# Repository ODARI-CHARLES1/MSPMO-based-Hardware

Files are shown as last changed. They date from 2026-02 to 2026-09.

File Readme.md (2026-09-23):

# MSPM0G350x Development Board

A hardware design for an Arduino UNO form-factor development board featuring the Texas Instruments MSPM0G350x Mixed-Signal Microcontroller with built-in CAN-FD interface.

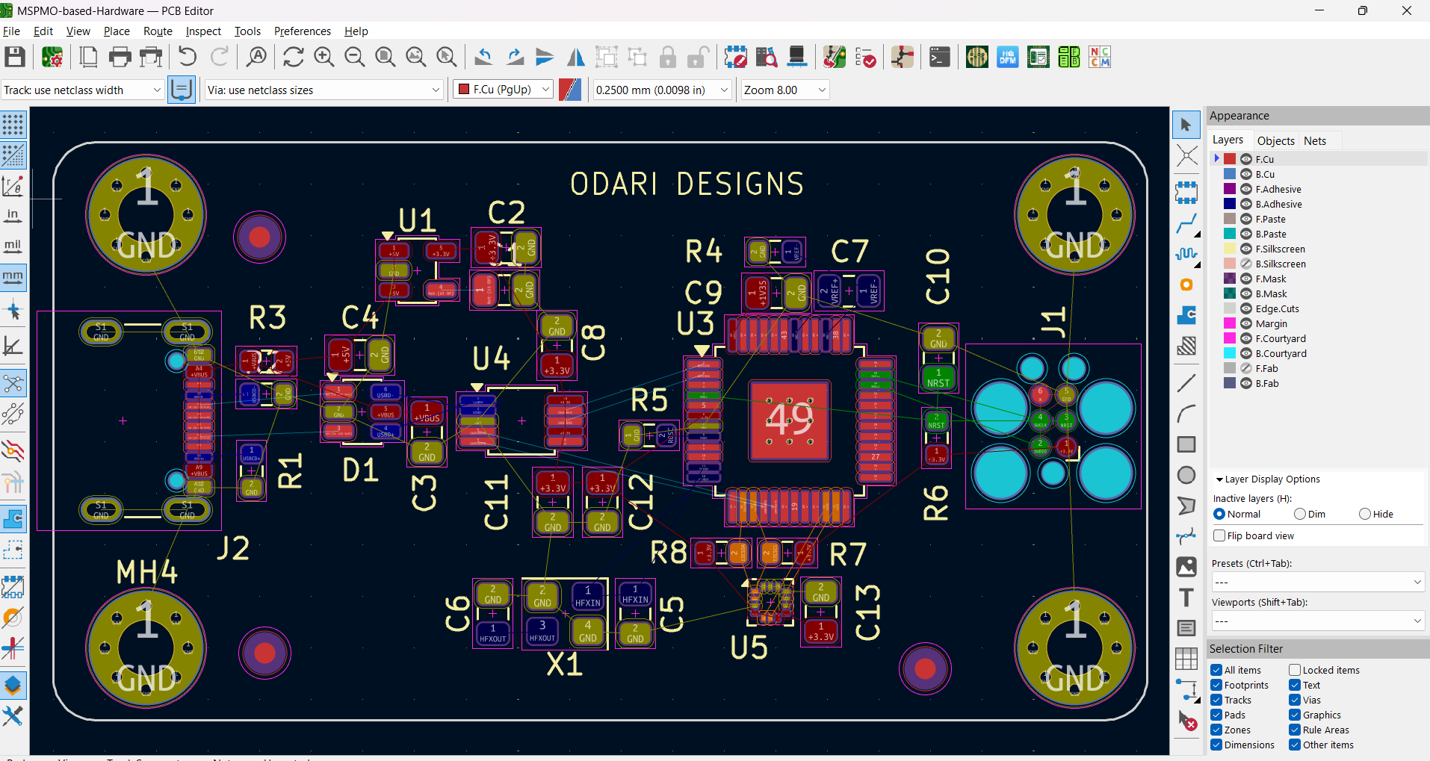
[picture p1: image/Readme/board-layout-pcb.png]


---

## Overview

This project contains the KiCad design files for a custom development board based on the Texas Instruments MSPM0G3507 MCU, featuring CAN-FD connectivity in a familiar Arduino UNO-compatible form factor.

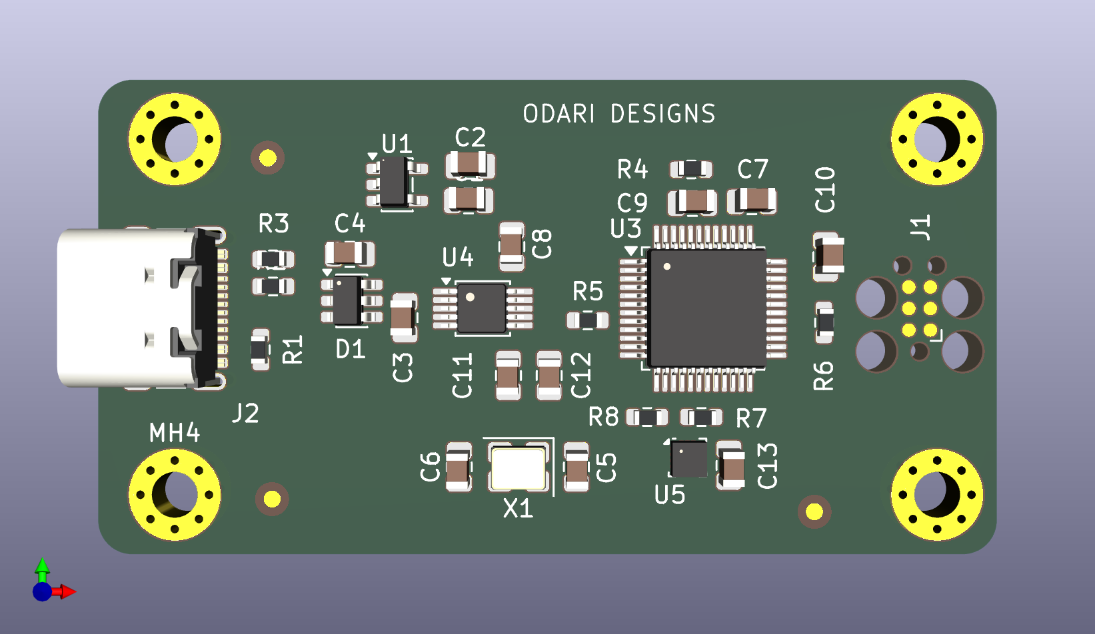
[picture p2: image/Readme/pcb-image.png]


---
## Features

### Microcontroller

- **MCU**: Texas Instruments MSPM0G3507 (or MSPM0G3506)
- **Core**: ARM Cortex-M0+ 32-bit processor
- **Clock Speed**: Up to 80 MHz
- **Flash Memory**: 128 KB (MSPM0G3507) / 64 KB (MSPM0G3506)
- **SRAM**: 32 KB

### Integrated Peripherals

- **CAN-FD Controller**: Built-in CAN-FD with up to 5 Mbps
- **ADC**: 12-bit Analog-to-Digital Converter (up to 20 channels)
- **DAC**: 12-bit Digital-to-Analog Converter (2 channels)
- **Timers**: Multiple 16-bit and 32-bit timers
- **PWM**: High-resolution PWM outputs
- **Communication**: UART, SPI, I2C, DMA

### Board Features

- **Form Factor**: Arduino UNO R3 compatible (2.54mm pitch, 3.3V logic)
- **Power Supply**: 7-12V DC barrel jack or USB-C (5V)
- **USB Interface**: Integrated USB-C for programming and debug
- **CAN Connector**: Standard DB9 or 4-pin header for CAN-FD
- **Power LED**: Power indicator
- **User LED**: Programmable status LED on GPIO pin

---

## Pinout

### Arduino-Compatible Headers

#### Power Pins

| Pin  | Function | Description |
| ---- | --- | --- |
| VIN  | Power Input | External power (7-12V) |
| 5V | 5V Output | Regulated 5V (max 500mA) |
| 3.3V | 3.3V Output | Regulated 3.3V (max 300mA) |
| GND  | Ground | Common ground |
| GND  | Ground | Common ground |
| AREF | Analog Ref  | Analog reference voltage |
| SDA  | I2C Data | I2C data line (PA10) |
| SCL  | I2C Clock | I2C clock line (PA11) |

#### Digital I/O Pins (Right Header)

| Pin | Arduino | MSPM0 Pin | Function |
| --- | --- | --- | --- |
| D0  | RX0 | PA8 | UART0 RX / GPIO |
| D1  | TX0 | PA9 | UART0 TX / GPIO |
| D2  | INT0 | PA7 | External Interrupt / GPIO |
| D3  | PWM | PA6 | PWM / GPIO |
| D4  | - | PA5 | GPIO |
| D5  | PWM | PA4 | PWM / GPIO |
| D6  | PWM | PA3 | PWM / GPIO |
| D7  | - | PA2 | GPIO |

#### Digital I/O Pins (Left Header)

| Pin | Arduino  | MSPM0 Pin | Function |
| --- | --- | --- | --- |
| D8  | - | PC5 | GPIO |
| D9  | PWM | PC4 | PWM / GPIO |
| D10 | SPI SS | PC3 | SPI CS / GPIO |
| D11 | SPI MOSI | PC2 | SPI MOSI / GPIO |
| D12 | SPI MISO | PC1 | SPI MISO / GPIO |
| D13 | SPI SCK  | PC0 | SPI SCK / GPIO  |

#### Analog Pins (Bottom Header)

| Pin | Arduino  | MSPM0 Pin | Function |
| --- | --- | --- | --- |
| A0  | ADC0 | PA26 | ADC Channel 0 |
| A1  | ADC1 | PA27 | ADC Channel 1 |
| A2  | ADC2 | PA28 | ADC Channel 2 |
| A3  | ADC3 | PA25 | ADC Channel 3 |
| A4  | ADC4/SDA | PA10 | ADC / I2C SDA |
| A5  | ADC5/SCL | PA11 | ADC / I2C SCL |

### CAN-FD Interface

| Pin | Function | Notes |
| ----- | --- | --- |
| CAN_H | CAN High | Requires 120Ω termination |
| CAN_L | CAN Low  | Requires 120Ω termination |
| GND | Ground | Signal ground |

---

## Electrical Specifications

| Parameter | Value |
| --- | --- |
| Operating Voltage | 3.3V (logic), 5V (USB power) |
| Input Voltage (Barrel) | 7-12V DC |
| Max Current (3.3V) | 300 mA |
| Max Current (5V USB) | 500 mA |
| I/O Voltage | 3.3V (5V tolerant inputs) |
| CAN-FD Speed | Up to 5 Mbps |
| Operating Temp | -40°C to 85°C |

---

## Mechanical Specifications

| Parameter | Value |
| --- | --- |
| Board Dimensions | 68.6mm × 53.3mm (UNO form factor) |
| Mounting Holes | 4× M3 holes (2.9mm diameter) |
| Header Pitch | 2.54mm (0.1") |
| PCB Thickness | 1.6mm |

---

## Getting Started

### Prerequisites

- Texas Instruments MSPM0 MCU SDK
- CMSIS-DAP or compatible debug probe
- Arduino IDE with MSPM0 support

### Programming

1. **Via Debugger**: Connect a CMSIS-DAP probe to the SWD pins (SWDIO, SWDCLK, GND)
2. **Via USB**: Use the built-in USB bootloader (if programmed)

### Software Setup

```bash
# Install MSPM0 SDK
git clone https://github.com/TexasInstruments/mspm0_sdk.git

# Install ARM GCC toolchain
# Download from: https://developer.arm.com/tools-and-software/open-source-software/developer-tools/gnu-toolchain/gnu-rm
```

---

## Development Tools

- **EDA**: KiCad 8.0+
- **MCU SDK**: TI MSPM0 SDK
- **IDE**: TI Code Composer Studio or VS Code with MSPM0 plugins
- **Programmer**: CMSIS-DAP compatible probe

---

## Project Structure

```
MSPMO-based-Hardware/
├── MSPMO-based-Hardware.kicad_pro    # KiCad project file
├── MSPMO-based-Hardware.kicad_sch    # Schematic
├── MSPMO-based-Hardware.kicad_pcb    # PCB layout
├── MSPMO-based-Hardware.kicad_prl    # Layout settings
├── MSPMO-based-Hardware.kicad_dru    # Design rules
└── Readme.md                         # This file
```

---

## Hardware Design

### Power Supply Circuit

- USB-C connector for 5V input
- Barrel jack for 7-12V DC input
- AMS1117-3.3 LDO for 3.3V regulation
- LM1117-5.0 LDO for 5V regulation (optional)

### CAN-FD Transceiver

- SN65HVD230 or MCP2562 CAN-FD transceiver
- 120Ω terminating resistor (selectable)
- ESD protection on CAN lines

### Additional Components

- Reset button
- Boot selector (for bootloader)
- Power LED (green)
- User LED (red, on PC7)
- Crystal oscillator (32.768 kHz for RTC)

---

## Programming Examples

### Basic Blink

```c
#include "ti_mspm0g3507.h"

int main(void) {
    // Configure PC7 as output (User LED)
    GPIOC->DIR_b.PIN7 = GPIO_DIR_OUT;
  
    while(1) {
        GPIOC->DOUT_BSET = (1 << 7);  // LED on
        delay_ms(500);
        GPIOC->DOUT_BCLR = (1 << 7);  // LED off
        delay_ms(500);
    }
}
```

### CAN-FD Transmit

```c
#include "ti_mspm0g3507.h"
#include "can.h"

int main(void) {
    CAN_Init(CAN_BAUD_500K);
  
    CAN_TxHeaderTypeDef txHeader;
    txHeader.Id = 0x123;
    txHeader.DLC = 8;
    txHeader.IDE = CAN_ID_STD;
    txHeader.FDF = CAN_FD_CAN;
  
    uint8_t data[8] = {0x01, 0x02, 0x03, 0x04, 0x05, 0x06, 0x07, 0x08};
  
    while(1) {
        CAN_SendMessage(&txHeader, data);
        delay_ms(1000);
    }
}
```

---

## License

This hardware design is provided as-is for educational and development purposes.

---

## References

- [TI MSPM0G3507 Datasheet](https://www.ti.com/lit/ds/symlink/mspm0g3507.pdf)
- [TI MSPM0 SDK Documentation](https://dev.ti.com/tirex/explore/node?node=AGJ7H6JRK1A-jhO1mH3k0pw__LATEST)
- [CAN-FD Specification](https://www.can-cia.org/can-fd/)
- [Arduino UNO R3 Reference Design](https://store.arduino.cc/arduino-uno-rev3)

---

## Support

For issues or questions:

- Open an issue on the project repository
- Check TI's E2E forums for MSPM0-specific questions

---

**Version**: 1.0
**Date**: February 2026
**Author**: Odari-Designs

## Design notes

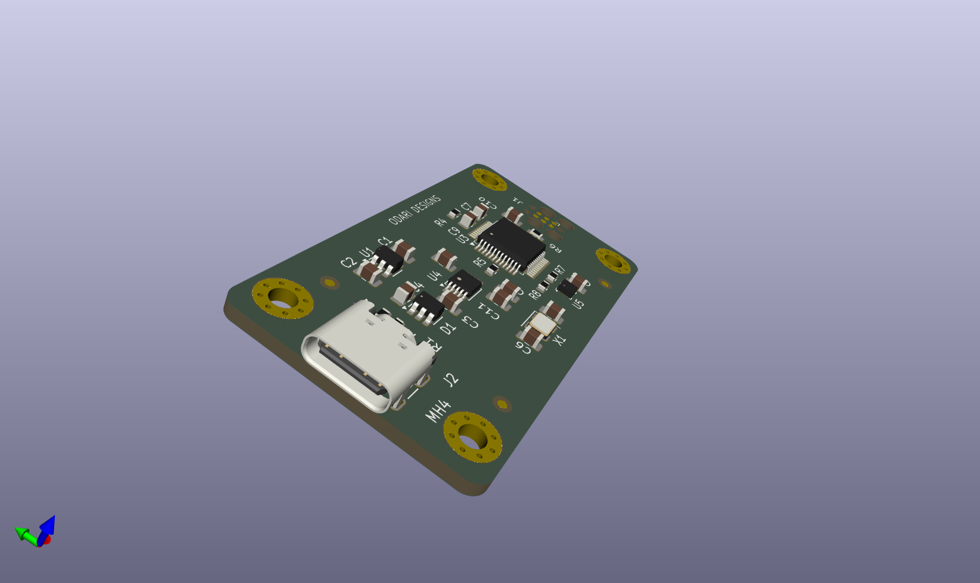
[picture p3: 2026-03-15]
Images/MSPMO-based-Hardware-01.png

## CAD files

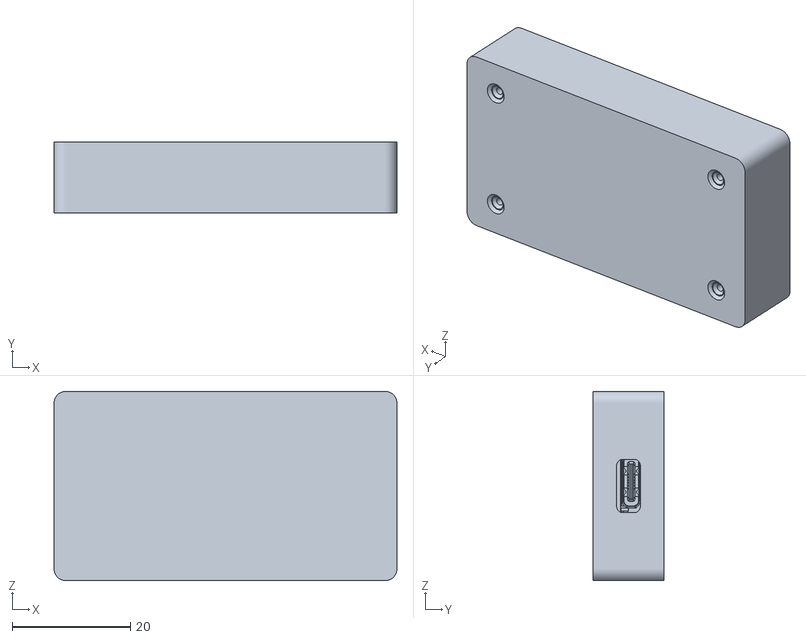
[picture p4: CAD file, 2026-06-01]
Enclosure_design/enclosure_assembly.stl
58.0 x 12.0 x 32.0

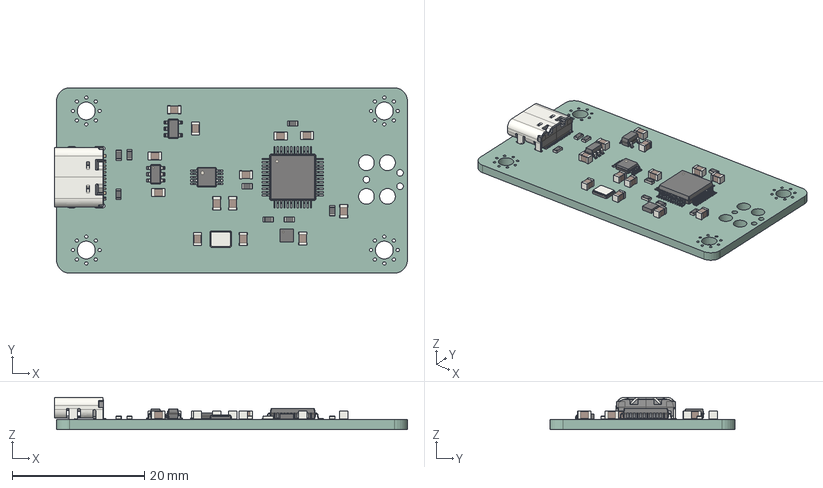
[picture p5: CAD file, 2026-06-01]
MSPMO-based-Hardware.step
53.3 x 28.0 x 4.91 mm
C_0805_2012Metric x 13
LGA-14_2x2mm_P0.35mm_LayoutBorder3x4y
USB_C_Receptacle_GCT_USB4105-xx-A_16P_TopMnt_Horizontal
R_0603_1608Metric x 8
Crystal_SMD_3225-4Pin_3.2x2.5mm
LQFP-48-1EP_7x7mm_P0.5mm_EP3.6x3.6mm
SOT-23-5
SOT-23-6
MSOP-10_3x3mm_P0.5mm
MSPMO-based-Hardware_PCB

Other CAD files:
Enclosure_design/MSPMO-based-Hardware.step
MSPMO-based-Hardware.stl

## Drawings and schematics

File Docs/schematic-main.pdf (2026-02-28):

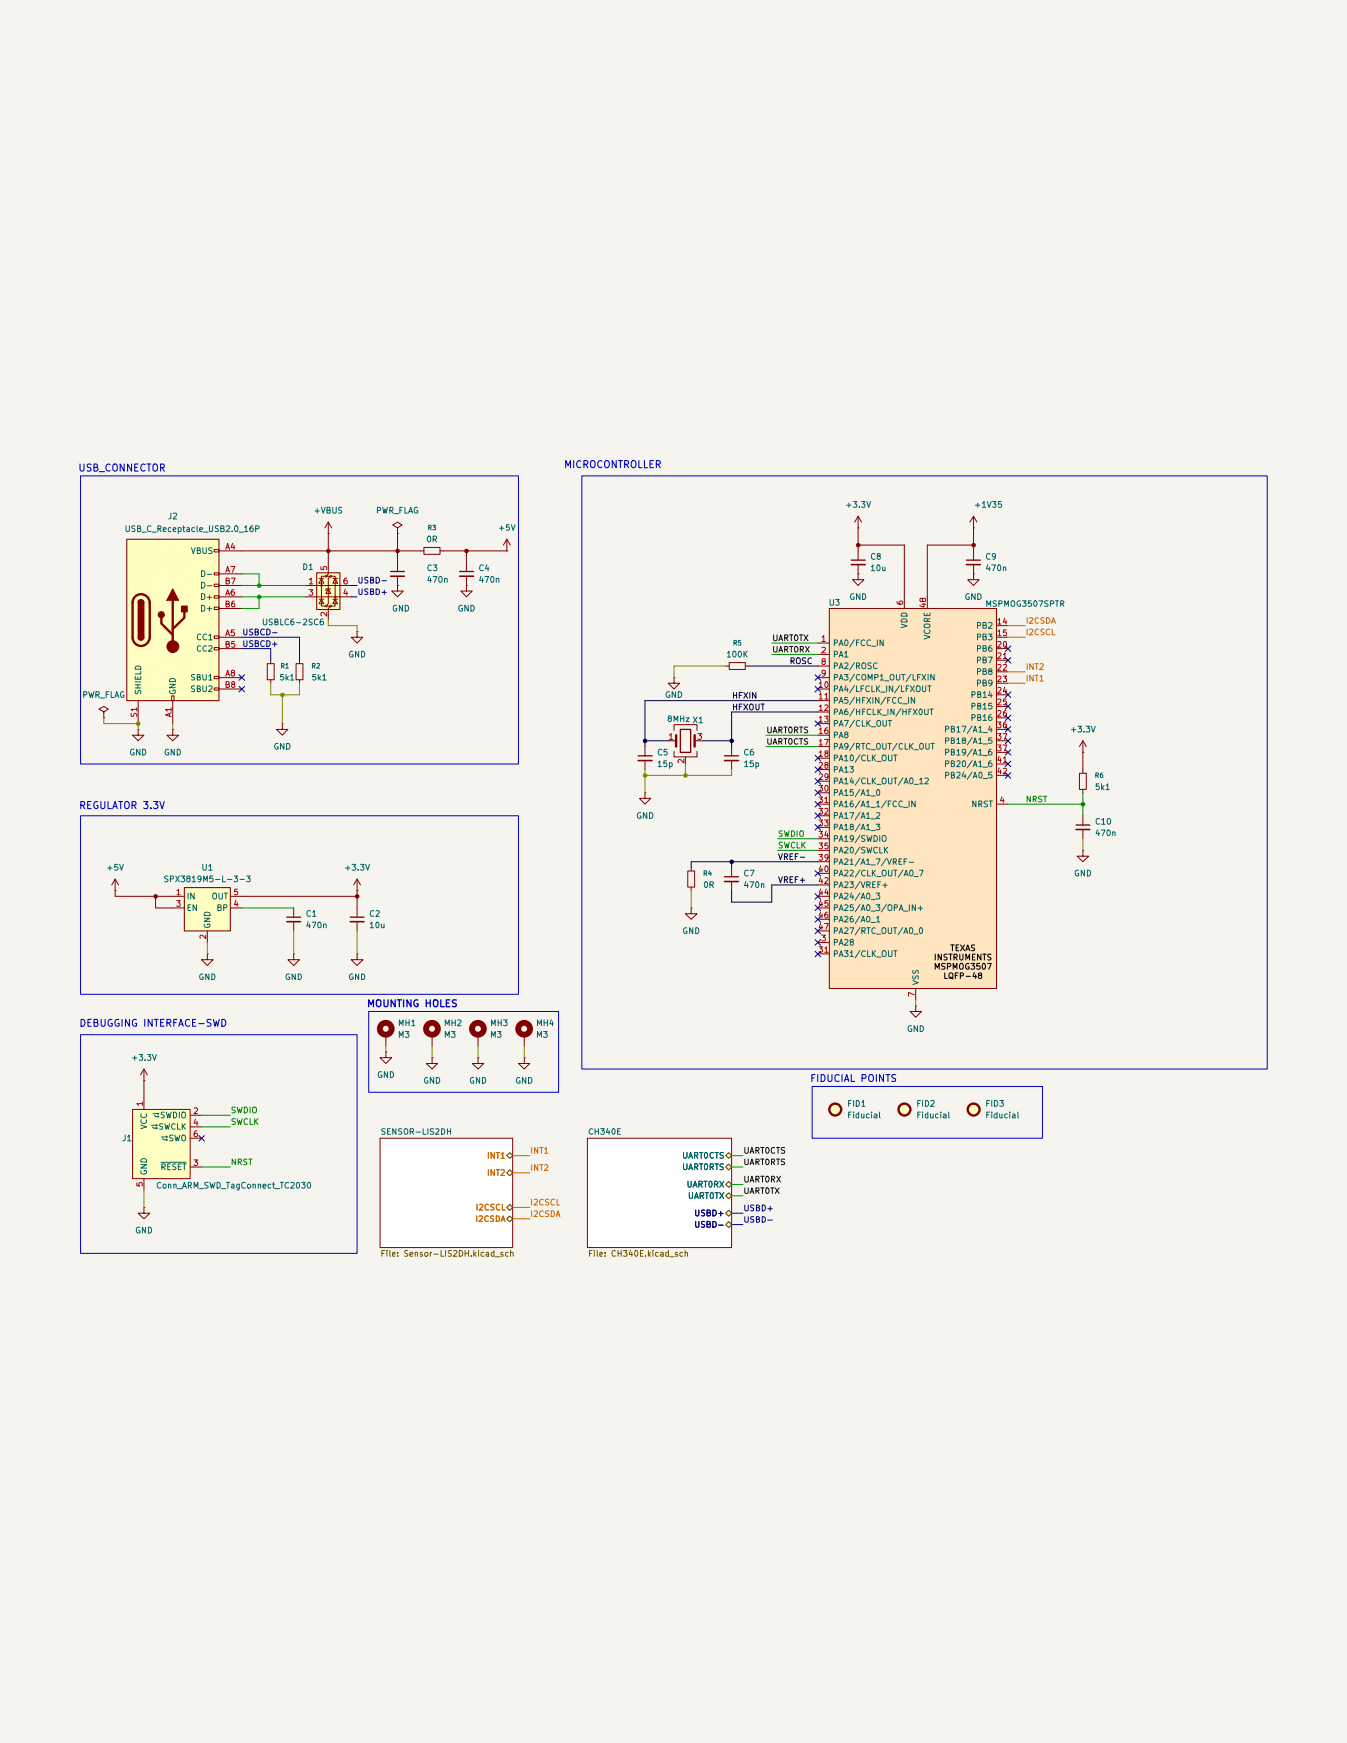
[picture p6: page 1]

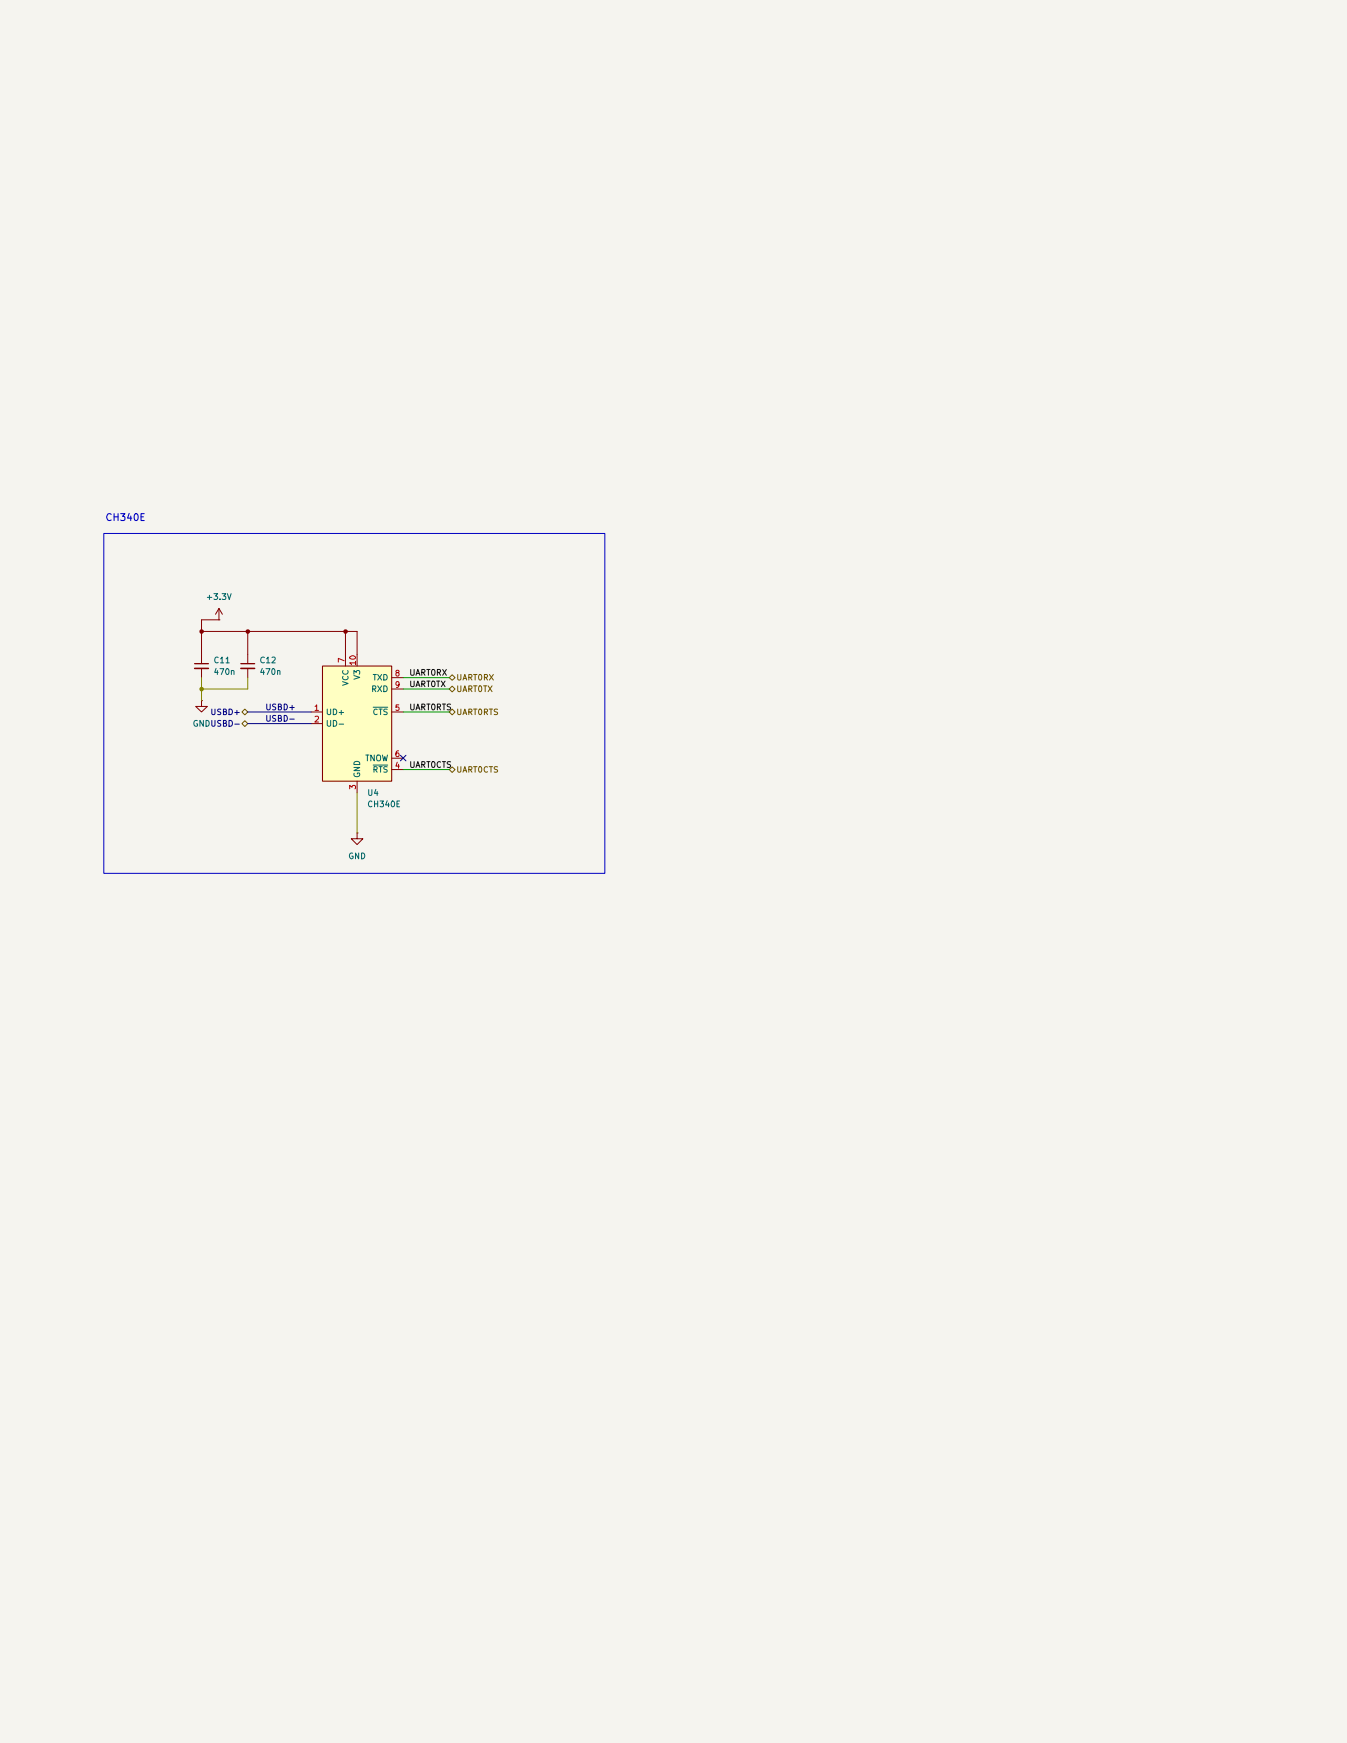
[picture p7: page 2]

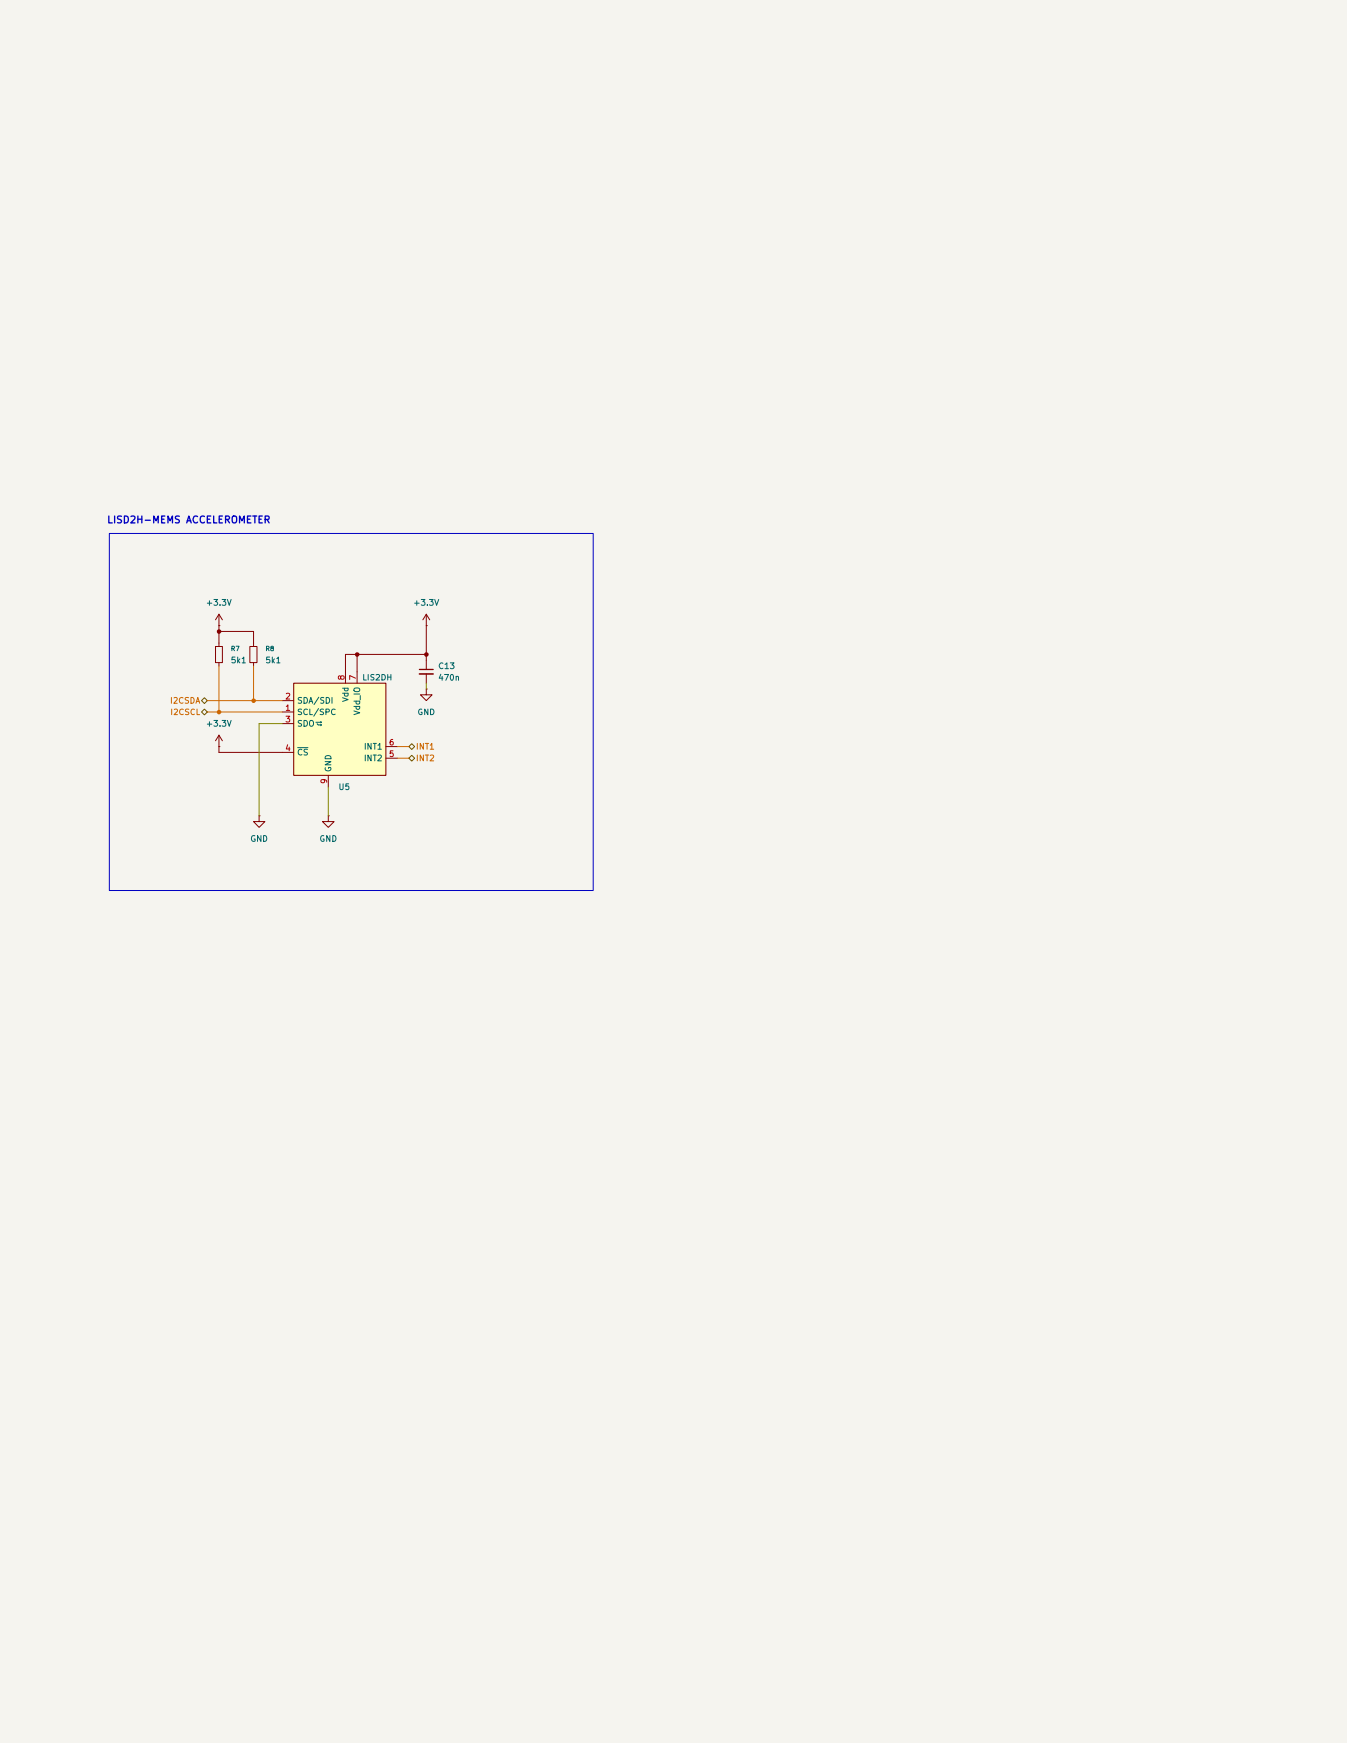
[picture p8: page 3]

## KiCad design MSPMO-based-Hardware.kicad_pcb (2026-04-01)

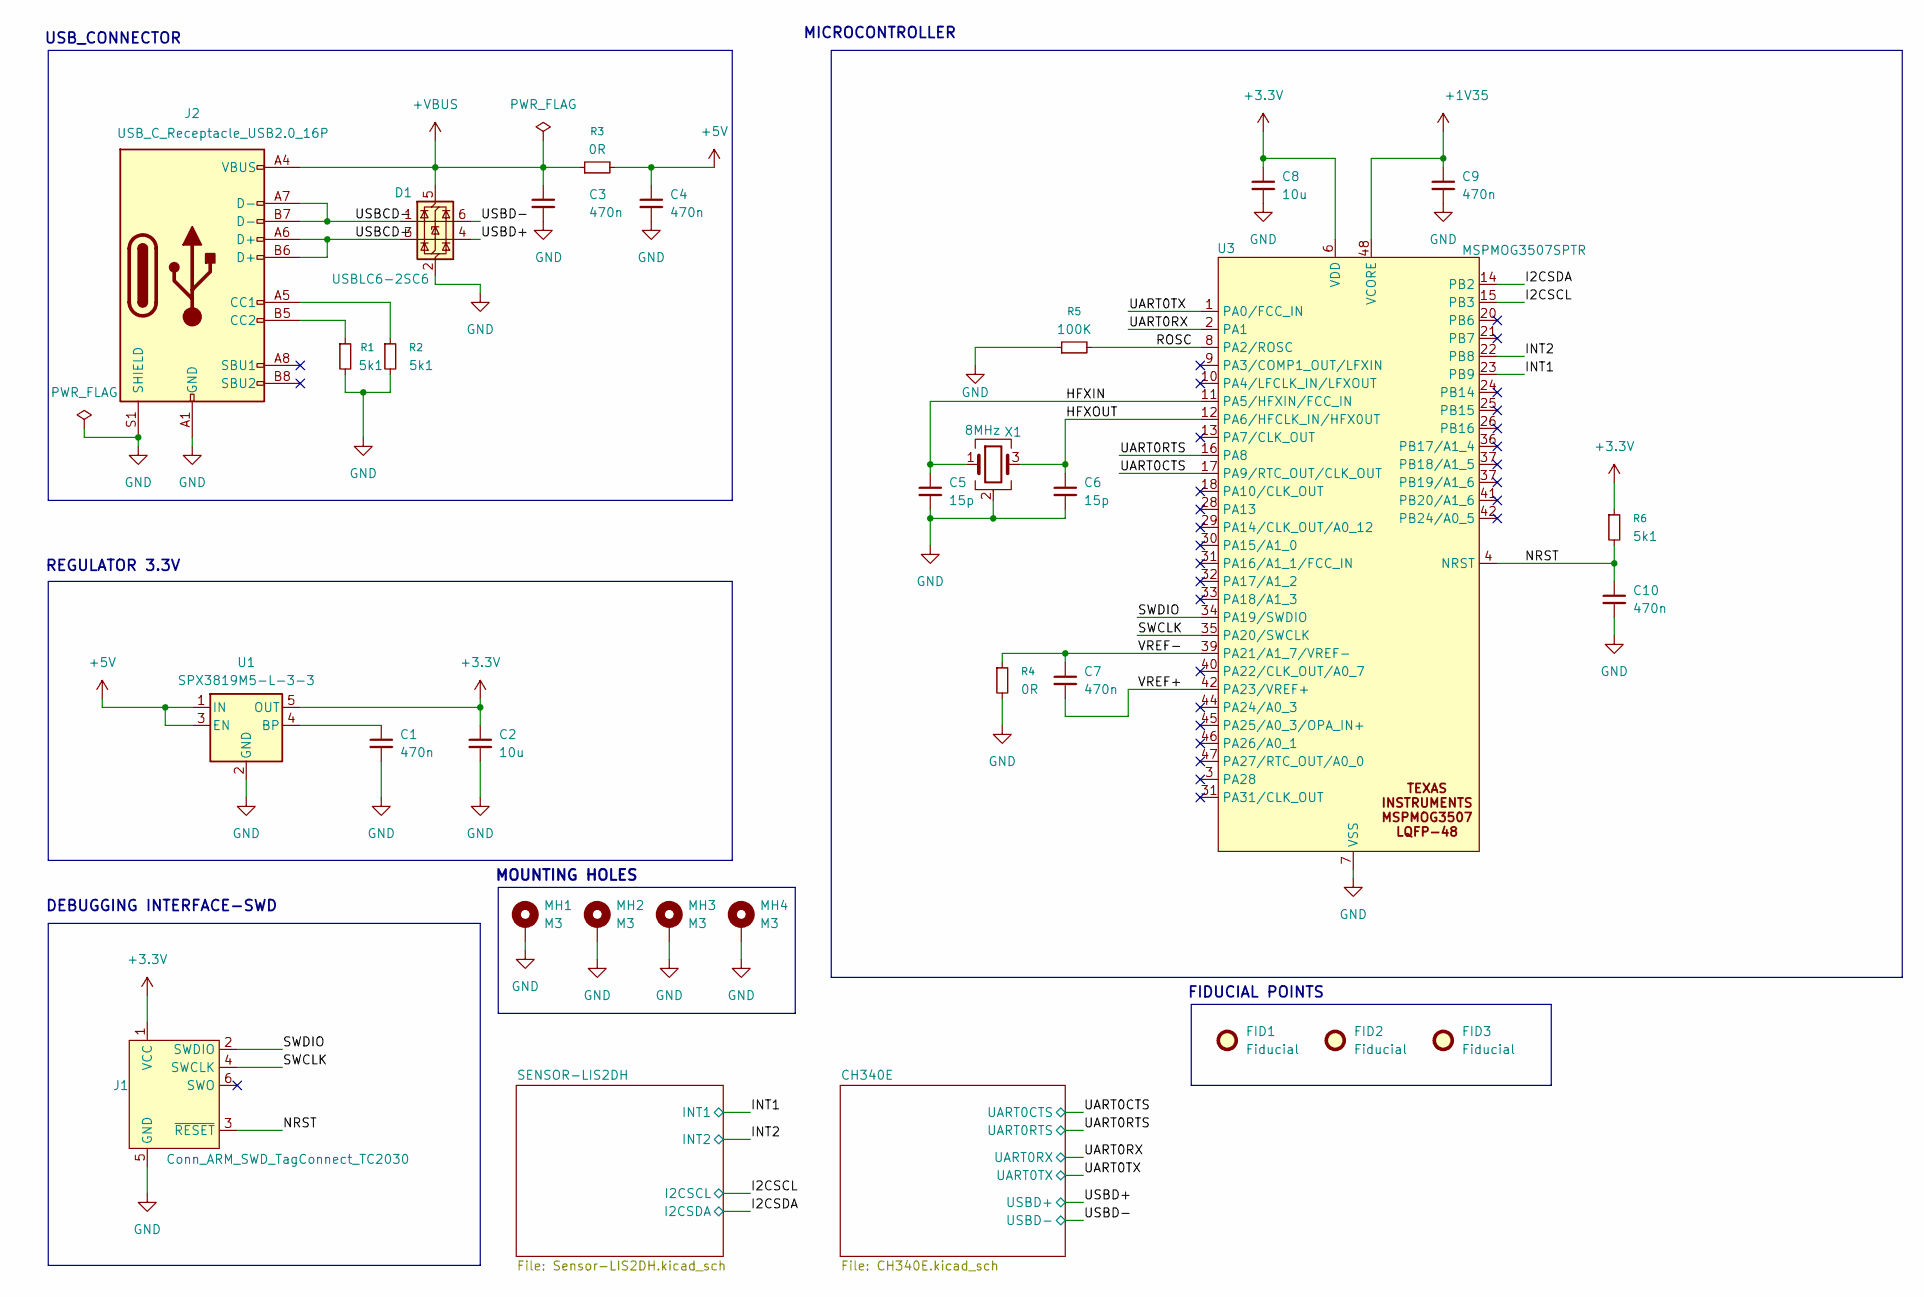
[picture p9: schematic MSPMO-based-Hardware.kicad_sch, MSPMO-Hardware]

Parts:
C1, C3, C4, C7, C9, C10: 470n; C_0805_2012Metric; Manufacturer part Number C0805T474K8RBLTU; LCSC C20859689
C2, C8: 10u; C_0805_2012Metric; Manufacturer part Number C0805C106K8PAC7210; LCSC C1882894
C5, C6: 15p; C_0805_2012Metric; Manufacturer part Number C0805T474K8RBLTU
D1: USBLC6-2SC6; SOT-23-6; Manufacturer part Number USBLC6-2SC6Y; LCSC C2969755
FID1, FID2, FID3: Fiducial; Fiducial_1mm_Mask2mm
J1: Conn_ARM_SWD_TagConnect_TC2030; Tag-Connect_TC2030-IDC-FP_2x03_P1.27mm_Vertical
J2: USB_C_Receptacle_USB2.0_16P; USB_C_Receptacle_GCT_USB4105-xx-A_16P_TopMnt_Horizontal; Manufacturer part Number GSB1C4621DS1HR; LCSC C20657289
MH1, MH2, MH3, MH4: M3; MountingHole_2.7mm_M2.5_Pad_Via
R1, R2, R6: 5k1; R_0603_1608Metric; Manufacturer Part Number TNPW06035K10BEEA; LCSC C2088892
R3, R4: 0R; R_0603_1608Metric; Manufacturer Part Number MCT06030C4702FP500; LCSC C1884633
R5: 100K; R_0603_1608Metric; Manufacturer Part Number TNPW0603100KFEEA; LCSC C2131840
U1: SPX3819M5-L-3-3; SOT-23-5; Manufacturer part Number SPX3819M5-L-3-3/TR
U3: MSPMOG3507SPTR; LQFP-48-1EP_7x7mm_P0.5mm_EP3.6x3.6mm_ThermalVias; Manufacturer Part Number MSPMOG3507SPTR; LCSC C22362630
X1: 8MHz; Crystal_SMD_3225-4Pin_3.2x2.5mm; Manufacturer part Number KC3225Z8.00000C1KX00; LCSC C1988275

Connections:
+1V35: C9.1, U3.48 (VCORE)
+3.3V: C2.1, C8.1, J1.1 (VCC), R6.1, U1.5 (OUT), U3.6 (VDD); also elsewhere on the board
+5V: C4.1, R3.2, U1.1 (IN), U1.3 (EN)
+VBUS: C3.1, D1.5 (VBUS), J2.A4 (VBUS), J2.A9 (VBUS), J2.B4 (VBUS), J2.B9 (VBUS), R3.1
/HFXIN: C5.1, U3.11 (PA5/HFXIN/FCC_IN), X1.1
/HFXOUT: C6.1, U3.12 (PA6/HFCLK_IN/HFX0UT), X1.3
/I2CSCL: U3.15 (PB3); also elsewhere on the board
/I2CSDA: U3.14 (PB2); also elsewhere on the board
/INT1: U3.23 (PB9); also elsewhere on the board
/INT2: U3.22 (PB8)
/NRST: C10.1, J1.3 (~RESET), R6.2, U3.4 (NRST)
/ROSC: R5.2, U3.8 (PA2/ROSC)
/SWCLK: J1.4 (SWCLK), U3.35 (PA20/SWCLK)
/SWDIO: J1.2 (SWDIO), U3.34 (PA19/SWDIO)
/UART0CTS: U3.17 (PA9/RTC_OUT/CLK_OUT); also elsewhere on the board
/UART0RTS: U3.16 (PA8); also elsewhere on the board
/UART0RX: U3.2 (PA1); also elsewhere on the board
/UART0TX: U3.1 (PA0/FCC_IN); also elsewhere on the board
/USBCD+: D1.3 (I/O2), J2.A6 (D+), J2.B6 (D+)
/USBCD-: D1.1 (I/O1), J2.A7 (D-), J2.B7 (D-)
/USBD+: D1.4 (I/O2); also elsewhere on the board
/USBD-: D1.6 (I/O1); also elsewhere on the board
/VREF+: C7.2, U3.42 (PA23/VREF+)
/VREF-: C7.1, R4.1, U3.39 (PA21/A1_7/VREF-)
GND: C1.2, C2.2, C3.2, C4.2, C5.2, C6.2, C8.2, C9.2, C10.2, D1.2 (GND), J1.5 (GND), J2.A1 (GND), J2.A12 (GND), J2.B1 (GND), J2.B12 (GND), J2.S1 (SHIELD), MH1.1, MH2.1, MH3.1, MH4.1, R1.2, R2.2, R4.2, R5.1, U1.2 (GND), U3.7 (VSS), X1.2 (G), X1.4 (G); also elsewhere on the board
unnamed: J2.A5 (CC1), R2.1
unnamed: J2.B5 (CC2), R1.1
unnamed: C1.1, U1.4 (BP)

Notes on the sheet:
DEBUGGING INTERFACE-SWD
USB_CONNECTOR
REGULATOR 3.3V
FIDUCIAL POINTS
MICROCONTROLLER
MOUNTING HOLES

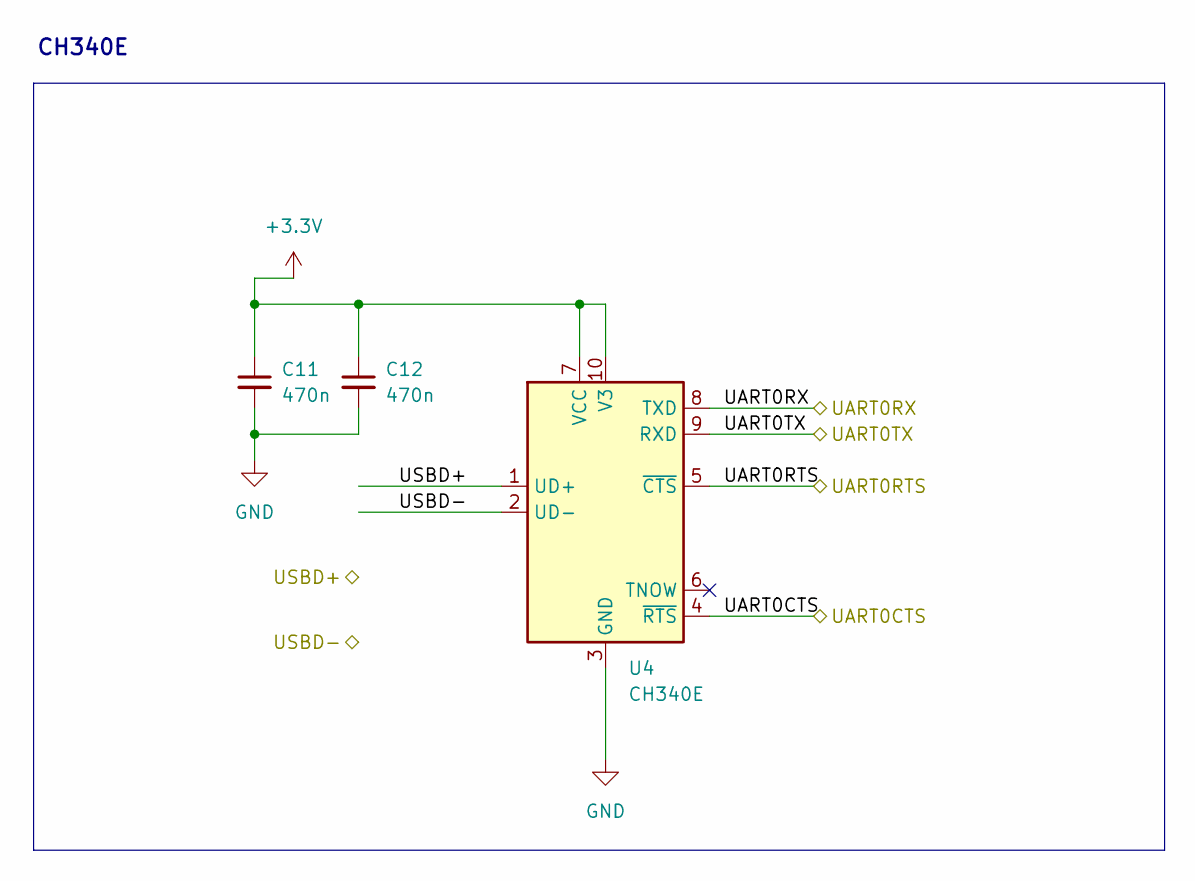
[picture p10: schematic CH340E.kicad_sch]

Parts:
C11, C12: 470n; C_0805_2012Metric; Manufacturer part Number C0805T474K8RBLTU; LCSC C20859689
U4: CH340E; MSOP-10_3x3mm_P0.5mm; Manufacturer part Number 5893; LCSC C99652

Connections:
+3.3V: C11.1, C12.1, U4.7 (VCC), U4.10 (V3); also elsewhere on the board
/UART0CTS: U4.4 (~RTS); also elsewhere on the board
/UART0RTS: U4.5 (~CTS); also elsewhere on the board
/UART0RX: U4.8 (TXD); also elsewhere on the board
/UART0TX: U4.9 (RXD); also elsewhere on the board
/USBD+: U4.1 (UD+); also elsewhere on the board
/USBD-: U4.2 (UD-); also elsewhere on the board
GND: C11.2, C12.2, U4.3 (GND); also elsewhere on the board

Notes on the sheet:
CH340E

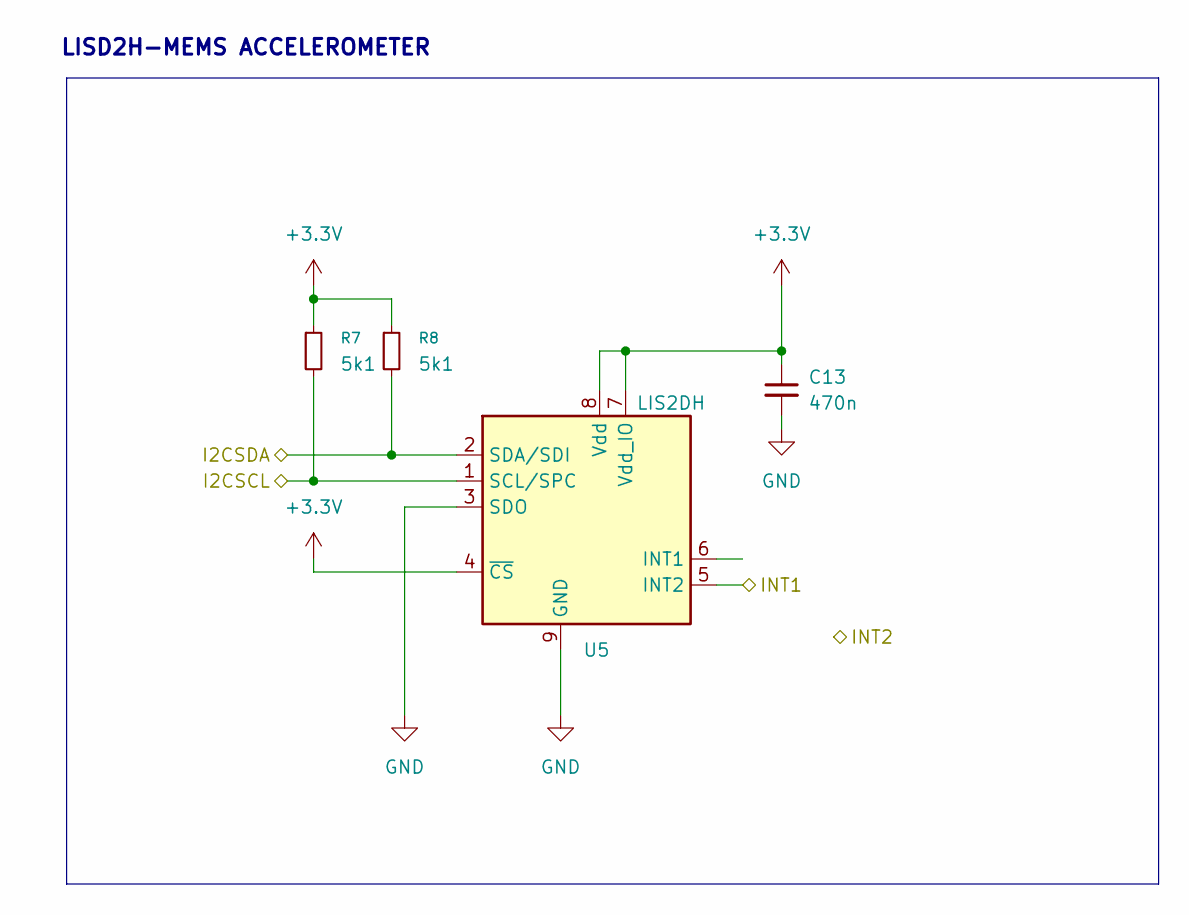
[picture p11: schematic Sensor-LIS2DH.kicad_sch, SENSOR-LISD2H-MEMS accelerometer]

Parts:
C13: 470n; C_0805_2012Metric; Manufacturer part Number C0805T474K8RBLTU; LCSC C20859689
R7, R8: 5k1; R_0603_1608Metric; Manufacturer Part Number TNPW06035K10BEEA; LCSC C2088892
U5: LIS2DH; LGA-14_2x2mm_P0.35mm_LayoutBorder3x4y; Manufacturer part Number LIS2DH12TR; LCSC C110926

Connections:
+3.3V: C13.1, R7.1, R8.1, U5.4 (~CS), U5.7 (Vdd_IO), U5.8 (Vdd); also elsewhere on the board
/I2CSCL: R7.2, U5.1 (SCL/SPC); also elsewhere on the board
/I2CSDA: R8.2, U5.2 (SDA/SDI); also elsewhere on the board
/INT1: U5.5 (INT2); also elsewhere on the board
GND: C13.2, U5.3 (SDO), U5.9 (GND), U5.10 (GND), U5.11 (GND), U5.12 (GND), U5.13 (GND), U5.14 (GND); also elsewhere on the board

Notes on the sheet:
LISD2H-MEMS ACCELEROMETER

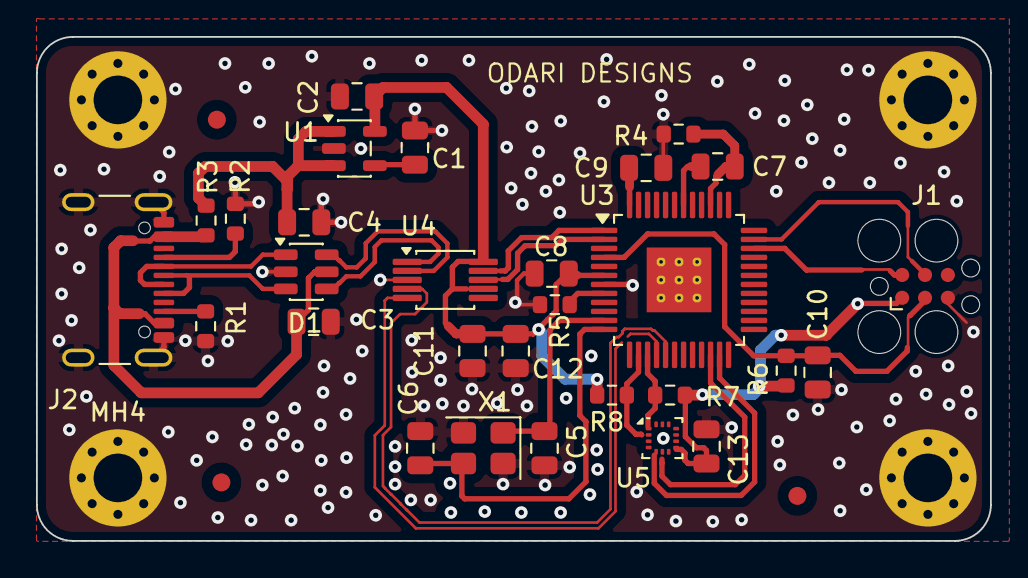
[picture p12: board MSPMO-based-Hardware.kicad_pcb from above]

Board: 2 copper layers, 53.0 x 28.0 mm, 36 parts (0 on the bottom side), 27 nets.

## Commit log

2026-02-16 created MSPMOG3507SPTR symbol
    [MSPMO-based-Hardware.kicad_sch]
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2026-02-22 chore(hardware): add passive components and update BOM configuration
    Add capacitors (C1-C6), resistors (R1-R3), and crystal (X1) to the MSPM0G3507 schematic with associated power decoupling and filtering circuitry. Update BOM export path to Docs folder and add distrib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
    [MSPMO-based-Hardware.kicad_sch]
2026-02-28 chore(hardware): adjust component positions in KiCad PCB layout
    Repositioned multiple passive components (resistors and capacitors) and IC to resolve silkscreen overlap and improve PCB layout density. Modified positions for C4, C9, C10, C11, C12, C13, R1, R3, R4, R5, R6, R7, U4, and J1 to optimize component spacing and silkscreen visibility.
    [MSPMO-based-Hardware.kicad_pcb]
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2026-02-28 chore(hardware): adjust C3 capacitor position in PCB layout
    [MSPMO-based-Hardware.kicad_pcb]
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2026-03-03 update the schematic file
    [MSPMO-based-Hardware.kicad_pcb, MSPMO-based-Hardware.kicad_sch]
2026-03-04 featardware): major(h PCB redesign with USB-C, SWD programming, and sensor integration
    Redesigned MSPM0-based hardware PCB with significant changes:
    - Added USB-C receptacle with ESD protection (USBLC6-2SC6)
    - Added Tag-Connect TC2030 SWD programming header
    - Added LIS2DH 3-axis accelerometer with I2C interface
    - Added CH340E USB-to-serial converter for UART debugging
    - Added SPX3819 LDO voltage regulator (3.3V output)
    - Relocated microcontroller and reorganized component placement
    - Added full PCB stackup configuration with FR4 dielectric specs
    - Added mounting holes and fiducial markers for manufacturing
    - Updated net connectivity (connected previously unconnected pins)
    - Added silkscreen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
    [MSPMO-based-Hardware.kicad_pcb]
2026-03-04 chore(hardware): update KiCad project settings with enhanced design rules and net class configuration
2026-03-04 feat(hardware): add fiducial markers and mounting holes to PCB schematic
    Add manufacturing aids to the KiCad schematic including:
    - Three fiducial markers (FID1, FID2, FID3) for SMT alignment during assembly
    - Four M3 mounting holes with connected pads (MH1-MH4) for secure PCB mounting
    - Associated GND connections and text labels for documentation
    - Also adds KLC compliance properties to various schematic components
    [MSPMO-based-Hardware.kicad_sch]
2026-03-04 fix(hardware): update LIS2DH sensor schematic with corrected routing and metadata
    - Adjust wire routing for INT1 signal path on Sensor-LIS2DH schematic
    - Update datasheet URL to STMicroelectronics lis2dh12.pdf
    - Add manufacturer, supplier, and part number metadata to component
    - Add KLC compliance properties (KLC_S3.3, KLC_S4.1) to symbol and footprint entries
    [Sensor-LIS2DH.kicad_sch]
2026-03-05 feat(hardware): add CH340E USB-to-Serial converter schematic
    Add CH340E USB-to-UART converter IC with associated decoupling capacitors
    and filtering components for USB connectivity. The circuit includes 470nF
    capacitors on USB lines, power conditioning, and UART signal connections.
    [CH340E.kicad_sch]
2026-03-05 feat(hardware): add net class configurations for I2C, UART, USB and new component sheets
    Add net class presets and pattern assignments for I2C, UART, and USB protocols in KiCad project. Include new sheets for CH340E USB-to-Serial converter and LIS2DH sensor. Relax ERC checks for pin driv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
2026-03-05 feat(hardware): add net class configurations and relax ERC settings
    Configure net class patterns for USB, UART, and I2C protocols with designated colors and wire widths. Add CH340E and SENSOR-LIS2DH sheets to the design hierarchy. Relax ERC constraints by changing pi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
    [MSPMO-based-Hardware.kicad_sch]
2026-03-05 feat(hardware): add CH340E USB-to-serial and LIS2DH sensor sub-sheets with I2C/UART connectivity
    - Add CH340E USB-to-serial converter sheet with UART0 and USB signals
    - Add LIS2DH accelerometer sensor sheet with I2C and interrupt pins
    - Add PWR_FLAG symbols for improved ERC compliance
    - Rename DEBUGGING INTERFACE to DEBUGGING INTERFACE-SWD
    - Rename USB_C to USB_CONNECTOR for clarity
    - Reorganize component placement and routing
    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
    [Sensor-LIS2DH.kicad_sch]
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2026-03-06 Update:add TC2030 for debugging interface
    [MSPMO-based-Hardware.kicad_sch]
2026-03-10 feat(hardware): add KLC compliance properties and supplier metadata to schematic components
    Adds KiCad Library Convention properties (KLC_S3.3, KLC_S4.1) to multiple components for compliance, and includes manufacturer, part number, and distributor links (Mouser, DigiKey, LCSC) to the CH340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
    [CH340E.kicad_sch]
2026-03-10 feat(hardware): add custom design rules for JLCPCB manufacturing
    Add MSPMO-based-Hardware.kicad_dru with DRC rules matching JLCPCB
    capabilities including track width, clearance, hole size, and
    silkscreen requirements for outer and inner layers.
2026-03-15 chore(hardware): reposition components and add design to PCB layout
    [MSPMO-based-Hardware.kicad_pcb]
2026-03-22 feat(hardware): add L2 GND ground plane zone to PCB layout
    - Added new bottom copper layer GND polygon zone (L2_GND) for improved ground connectivity
    - Updated zone connection settings for GND pin to optimize electrical performance
    - These changes enhance the PCB's grounding design and signal integrity
    [MSPMO-based-Hardware.kicad_pcb]
2026-03-22 fix(hardware): update pad dimensions for PCB footprint
2026-03-23 feat(hardware): add routing vias and reposition PCB components
    Add approximately 50 new vias with copper trace segments to improve PCB routing connectivity. Reposition multiple components including capacitors (C2-C13), resistors (R1-R5, R8), and IC (U1) to optim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
    [MSPMO-based-Hardware.kicad_pcb]
2026-03-23 fix(hardware): update PCB routing clearance and track width constraints
    - Reduce clearance from 0.2mm to 0.152mm for the 12-bit bus class
    - Add 0.3mm and 0.4mm track width options while removing 0.75mm
    - These changes optimize PCB routing rules for the bus width configuration
2026-03-30 fix(hardware): rearrange hierarchical labels in CH340E schematic
    Swapped positions of USBD-/USBD+ with UART0RTS/UART0CTS signal labels and adjusted their orientation and placement coordinates in the KiCad schematic.
    [CH340E.kicad_sch]
2026-03-30 fix(hardware): remap USB differential signals to UART flow control pins
    Renamed hierarchical labels in CH340E schematic to properly map USB D+/D- signals to UART0 RTS/CTS pins, correcting the signal routing configuration.
    [MSPMO-based-Hardware.kicad_pcb]
2026-03-30 fix(hardware): update PCB design rules and track width constraints
    Updates KiCad design rules by reducing minimum clearance from 0.152mm to 0.1mm, adding new track widths (0.05, 0.1, 0.15, 0.25mm), and adjusting differential pair width from 0.2mm to 0.25mm to improve routing flexibility.
2026-03-30 fix(hardware): reposition USB CDC differential signal labels in schematic
    [MSPMO-based-Hardware.kicad_sch]
2026-03-30 fix(hardware): rearrange LIS2DH schematic hierarchical labels
    [Sensor-LIS2DH.kicad_sch]
2026-04-01 fix(hardware): reposition components and optimize PCB routing
    - Relocated J1 Tag-Connect header and J2 USB-C connector to resolve routing conflicts
    - Adjusted resistor and capacitor positions (R2, R3, R6, R8, C3, C6, C7, C9, C10, C13)
    - Realigned U5 LIS2DH12 accelerometer for better placement
    - Added new vias and net segments to improve signal routing
    - Expanded GND copper pours on both F.Cu and B.Cu layers
    [MSPMO-based-Hardware.kicad_pcb]
2026-04-01 fix(hardware): update BOM export path to parent directory
2026-04-01 fix(hardware): reposition INT2 hierarchical label in LIS2DH schematic
    [Sensor-LIS2DH.kicad_sch]
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2026-06-01 build(hardware): add STEP model for mechanical integration
    Include the MSPMO-based-Hardware.step file to enable 3D CAD workflows and mechanical assembly verification.
    [MSPMO-based-Hardware.step]
2026-06-01 feat(hardware): add STL mesh for 3D printing
    Add the MSPMO-based-Hardware.stl file to support rapid prototyping and 3D printing workflows.
    [MSPMO-based-Hardware.stl]
2026-06-01 build(enclosure): add STEP model for mechanical design
    Include the MSPMO-based-Hardware.step file to facilitate CAD integration and enclosure design workflows.
    [MSPMO-based-Hardware.step]
2026-06-01 feat(enclosure): add assembly STL mesh
    Add the STL mesh file for the enclosure assembly to support 3D printing workflows.
    [enclosure_assembly.stl]
2026-08-16 Update CH340E schematic file format
    [CH340E.kicad_sch]
